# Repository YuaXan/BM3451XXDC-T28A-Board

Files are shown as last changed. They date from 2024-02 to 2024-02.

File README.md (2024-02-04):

<div align="center">
<h1>
<a href="https://github.com/YuaXan/BM3451XXDC-T28A-Board">BM3451XXDC-T28A-Board</a></h1>

**Rechargeable battery protection board based on BM3451 IC**
______________________________________________________________________








</div>

## Product Introduction
The board uses `BM3451XXDC-T28A` to protect 3/4/5 cells rechargeable battery pack. the IC works constantly to monitor each cell’s voltage, the current of charge or discharge, and the temperature of the environment to provide overcharge, over-discharge, discharge overcurrent, short circuit, charge overcurrent, and over-temperature protections, etc. Besides, it also can change the protection delay time of overcharge, over-discharge, and discharge overcurrent by setting the external capacitors.
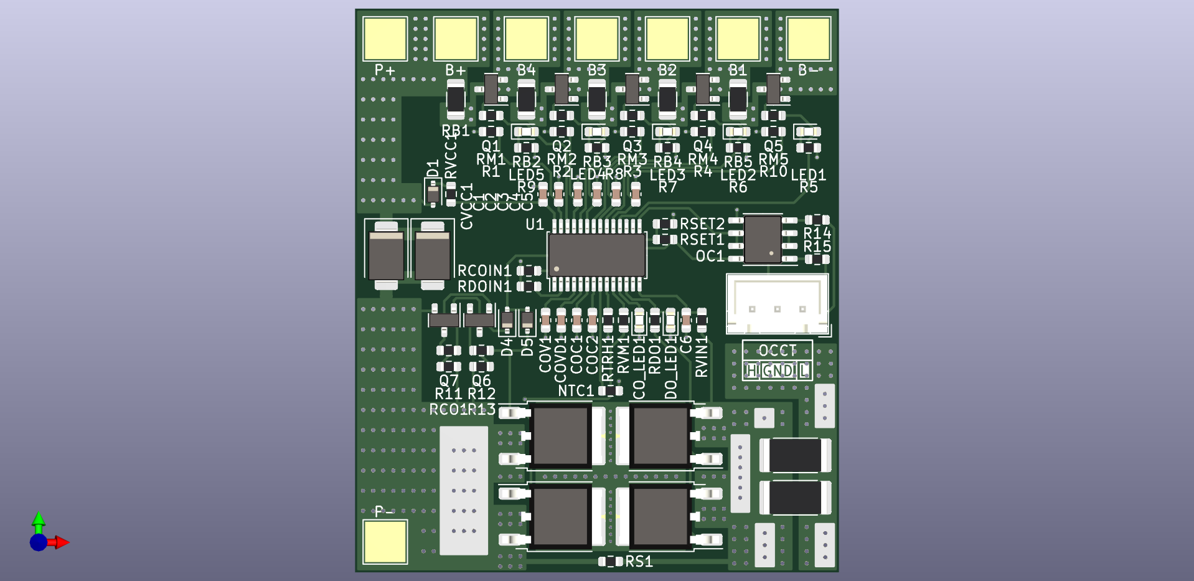
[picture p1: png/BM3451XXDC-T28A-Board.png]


## Application Scenarios
1. Power tools
2. Electric bicycle
3. UPS applications
4. etc.

## Product Description
The board's power supply voltage range is 5-30V, charge or discharge current MAX is 30A. 

The four MOSFET `Q8`, `Q9`, `Q10`, `Q11` and tow jepsun current resistor `RSENSE1` and `RSENSE2` can be replaced to achieve higher current output. 
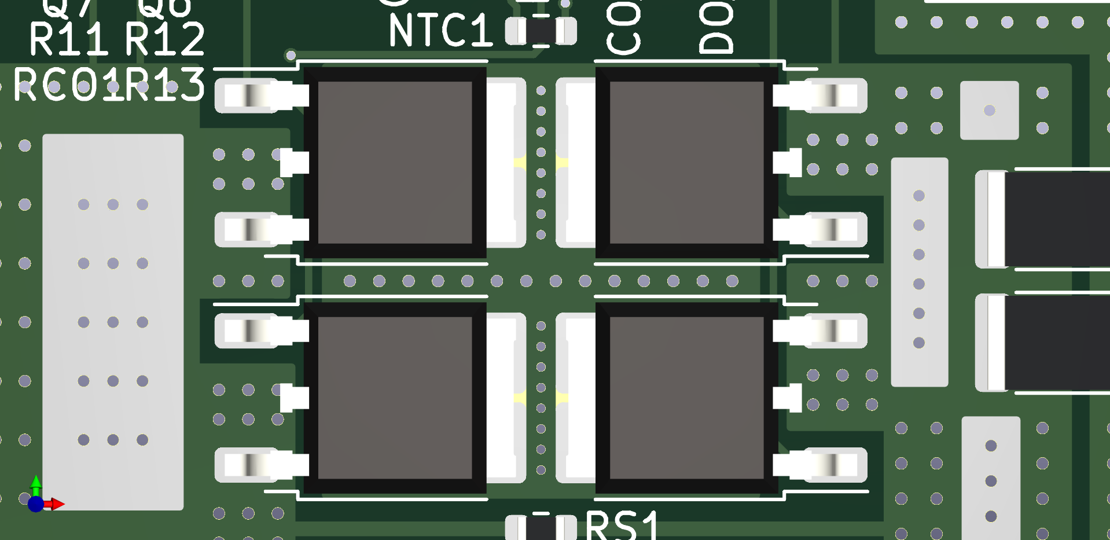
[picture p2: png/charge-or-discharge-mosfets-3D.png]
Charge or discharge mosfets 3D


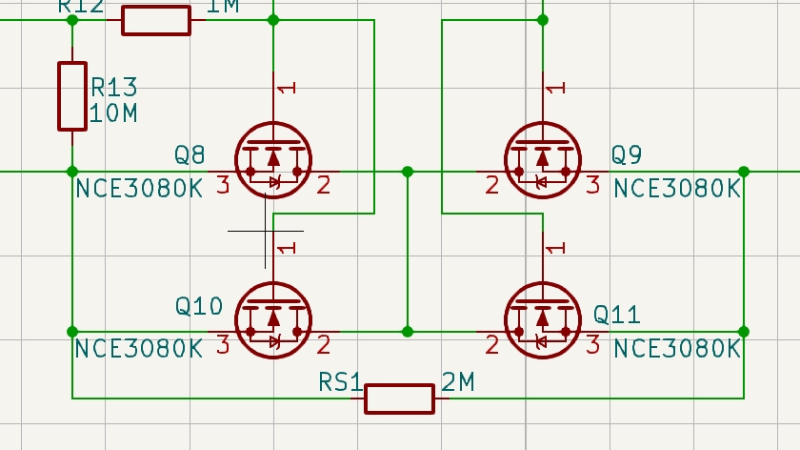
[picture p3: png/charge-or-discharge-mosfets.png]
Charge or discharge mosfets


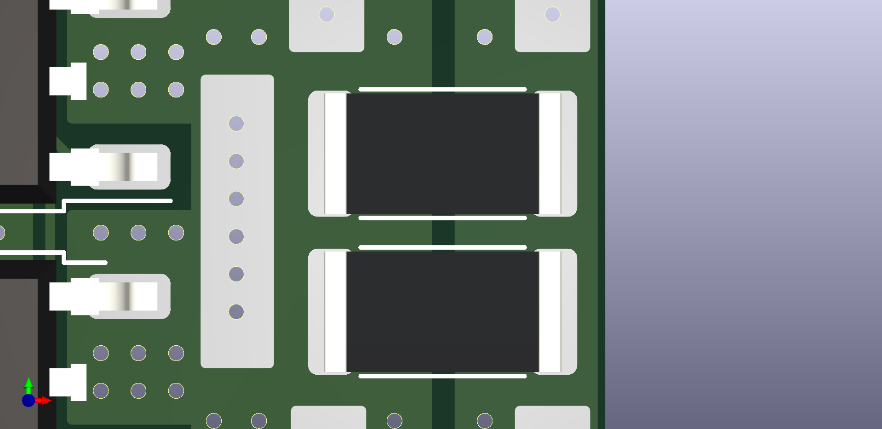
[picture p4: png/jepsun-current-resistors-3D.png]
Jepsun current resistors 3D


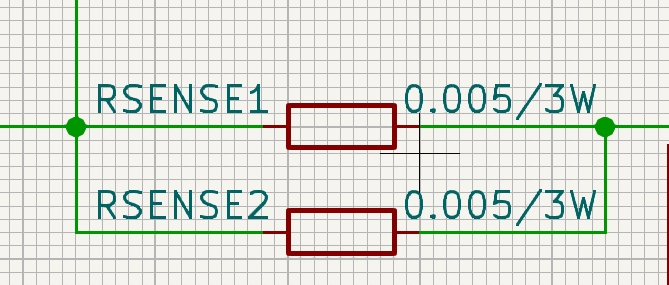
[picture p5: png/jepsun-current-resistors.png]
Jepsun current resistors


---

Select the number of cells based on whether `RSET1` and `RSET2` are mounted with 0Ω resistors.

When `RSET1` and `RSET2` all not mounting with 0Ω resistors leads to the `SET` pin in a floating state, and the board can connect 5 cells. 
When `RSET1` is mounting with resistors, `RSET2` is not mounting with resistors, and short circuits `B1` and `B-`, the board can connect 4 cells.
When `RSET1` is not mounting with resistors, and `RSET2` is mounting with resistors, and short circuits `B2`, `B1`, and `B-`, the board can connect 3 cells.

**[Warning]: Not `RSET1` and `RSET2` all to mounting with 0Ω resistors, this behavior will cause a short circuit**

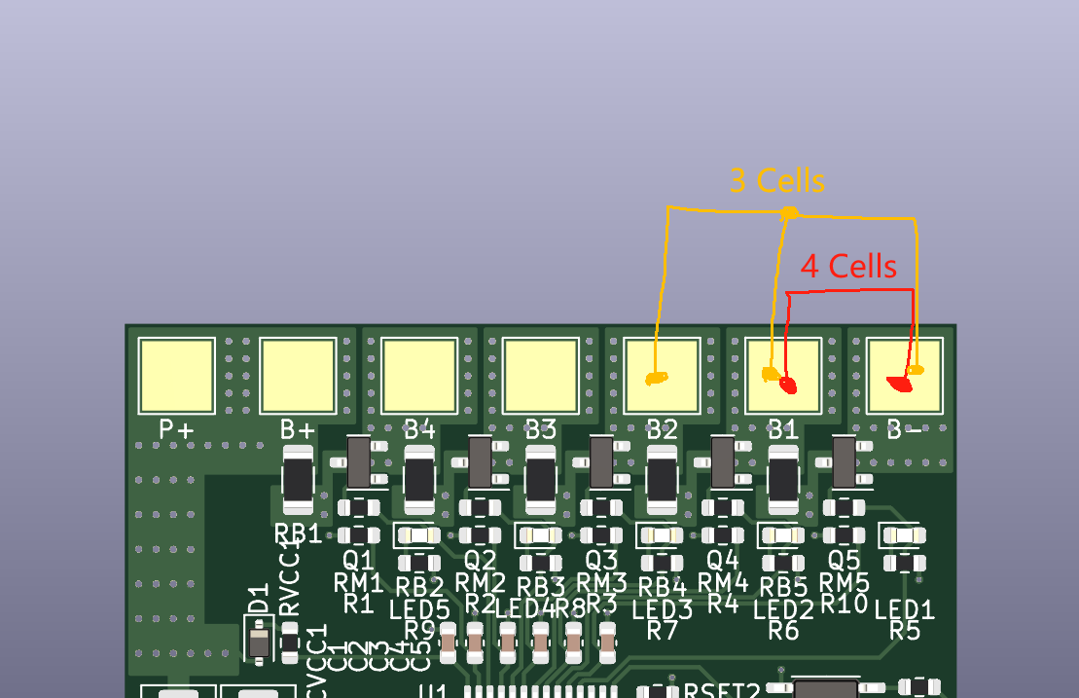
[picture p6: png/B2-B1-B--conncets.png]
B2/B1/B- Conncets


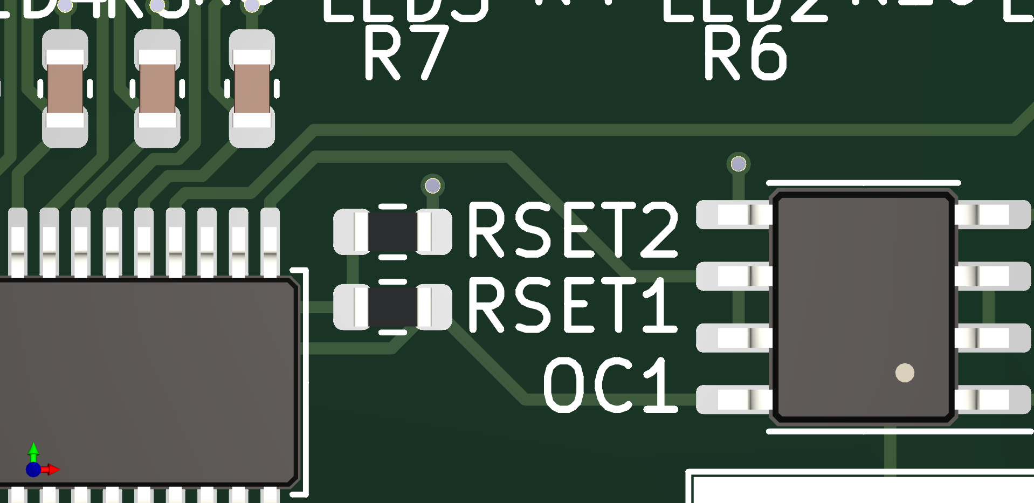
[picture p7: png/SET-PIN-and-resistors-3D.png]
SET PIN and resistors 3D


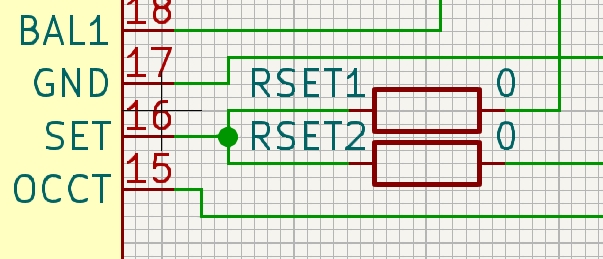
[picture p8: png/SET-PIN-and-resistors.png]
SET PIN and resistors


3/4/5 cells application selection

---

There are five LEDs to monitor the balancing status of the cells. When one of the LEDs is lit, it means that the corresponding cell is starting to balance. 
 
`LED1`, `LED2`, `LED3`, `LED4`, and `LED5` correspond to `B1`, `B2`, `B3`, `B4`, and `B5` respectively:
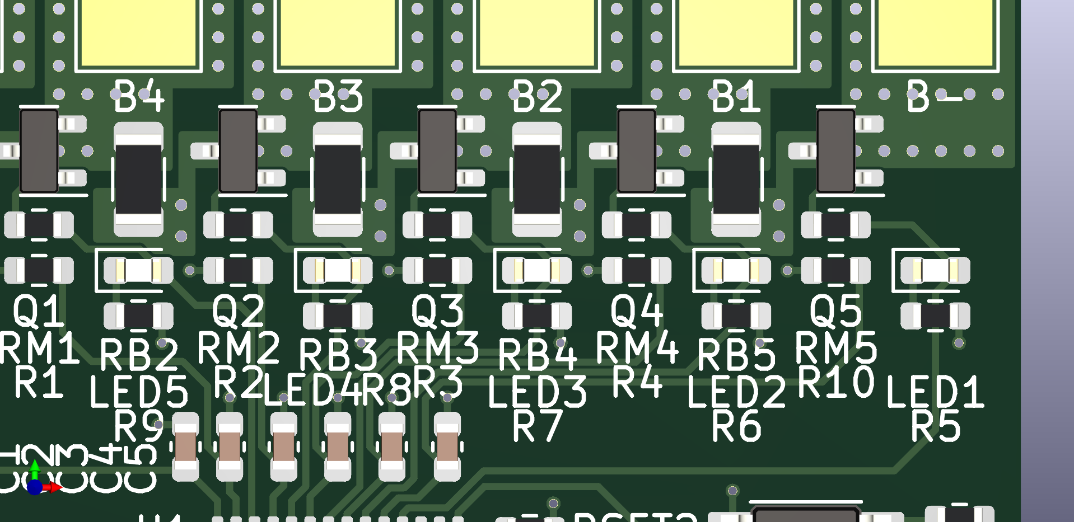
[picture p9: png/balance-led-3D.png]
balance led 3D


 ---
 
At the same time, the `DO` and `CO` pins correspond to `DO_LED1` and `CO_LED1` respectively. This allows you to check the discharge and charge status. 
 
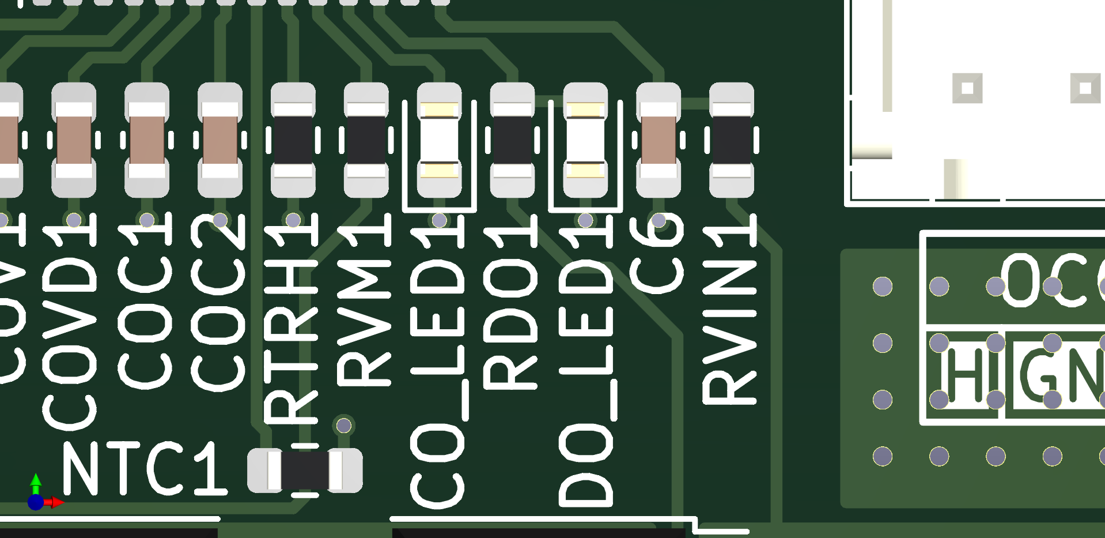
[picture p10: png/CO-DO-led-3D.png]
CO DO led 3D


 ---
 
Safe and reliable by providing control discharge overcurrent release terminals with optical coupler.

Control of `OCCT` pin is via `XH P2.5mm 3pin` terminal.

**[Warning]: The `OCCT` pin has not been tested. Usage instructions are not provided in the datasheet. Usage instructions will be provided after board testing.**

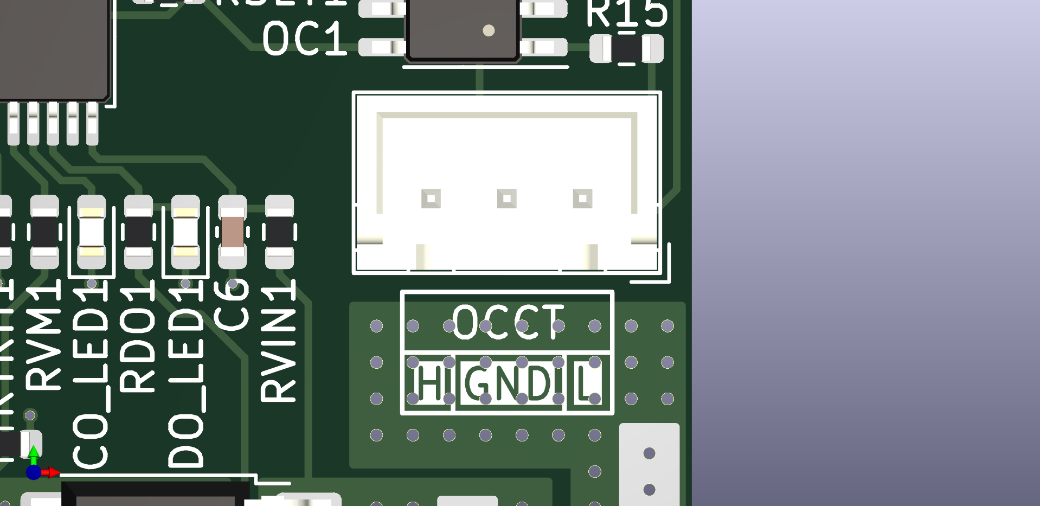
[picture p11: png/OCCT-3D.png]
OCCT 3D


## Instruction Manual
The board connection diagram is shown in the image.
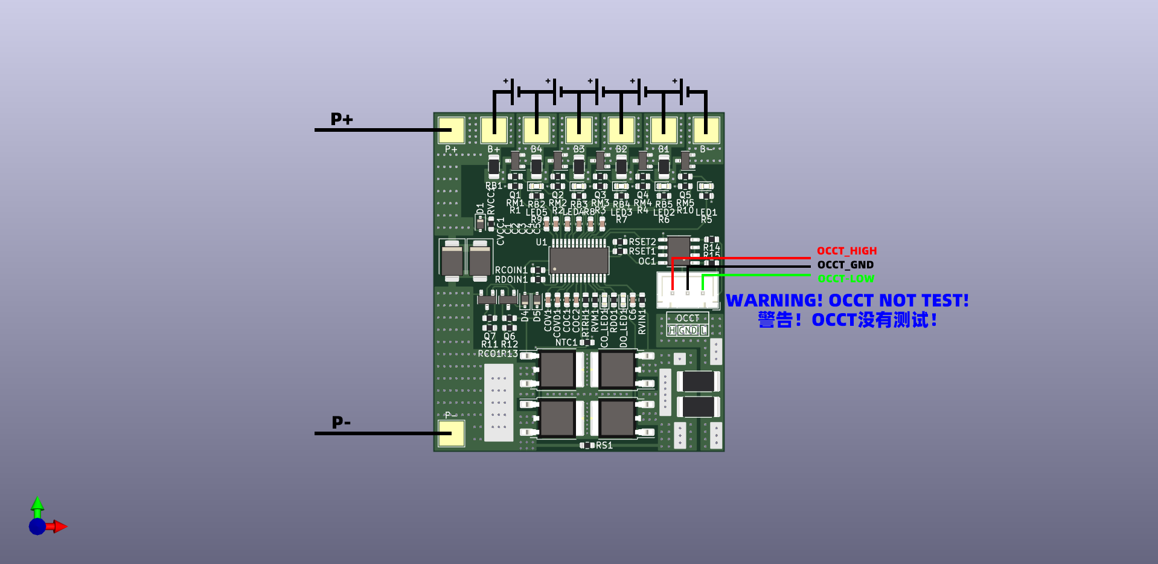
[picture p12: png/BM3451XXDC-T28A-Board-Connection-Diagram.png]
BM3451XXDC-T28A-Board Connection Diagram


## TODO
- [ ] The board is manufactured.
- [ ] The board is testing.
- [ ] Know how `OCCT` works.
- [ ] The donation channel is open.

## Contributions
Every contribution to this repository is highly appreciated! If you spot any bug or problem, open a issue or pull request so that it can be rectified for everyone.

For feature requests: Please open a issue and I'll add the feature in a future release once I get some time in my hands.

## Donors
The donation channel is not currently open, so stay tuned.

## License
For e-enthusiasts or geeks, follow the [CC-BY-NC-SA 4.0](/LICENSE.txt) license. For contributors and donors you can follow the [CC-BY 4.0](/LICENSE-CC-BY-4.0.txt) license, which means that commercial use is supported and distributed freely.

## Information
[BM3451XXDC-T28A DataSheet](http://www.bydmicro.com/params/field/preview/PDF_PRODUCT_202304141002.pdf)

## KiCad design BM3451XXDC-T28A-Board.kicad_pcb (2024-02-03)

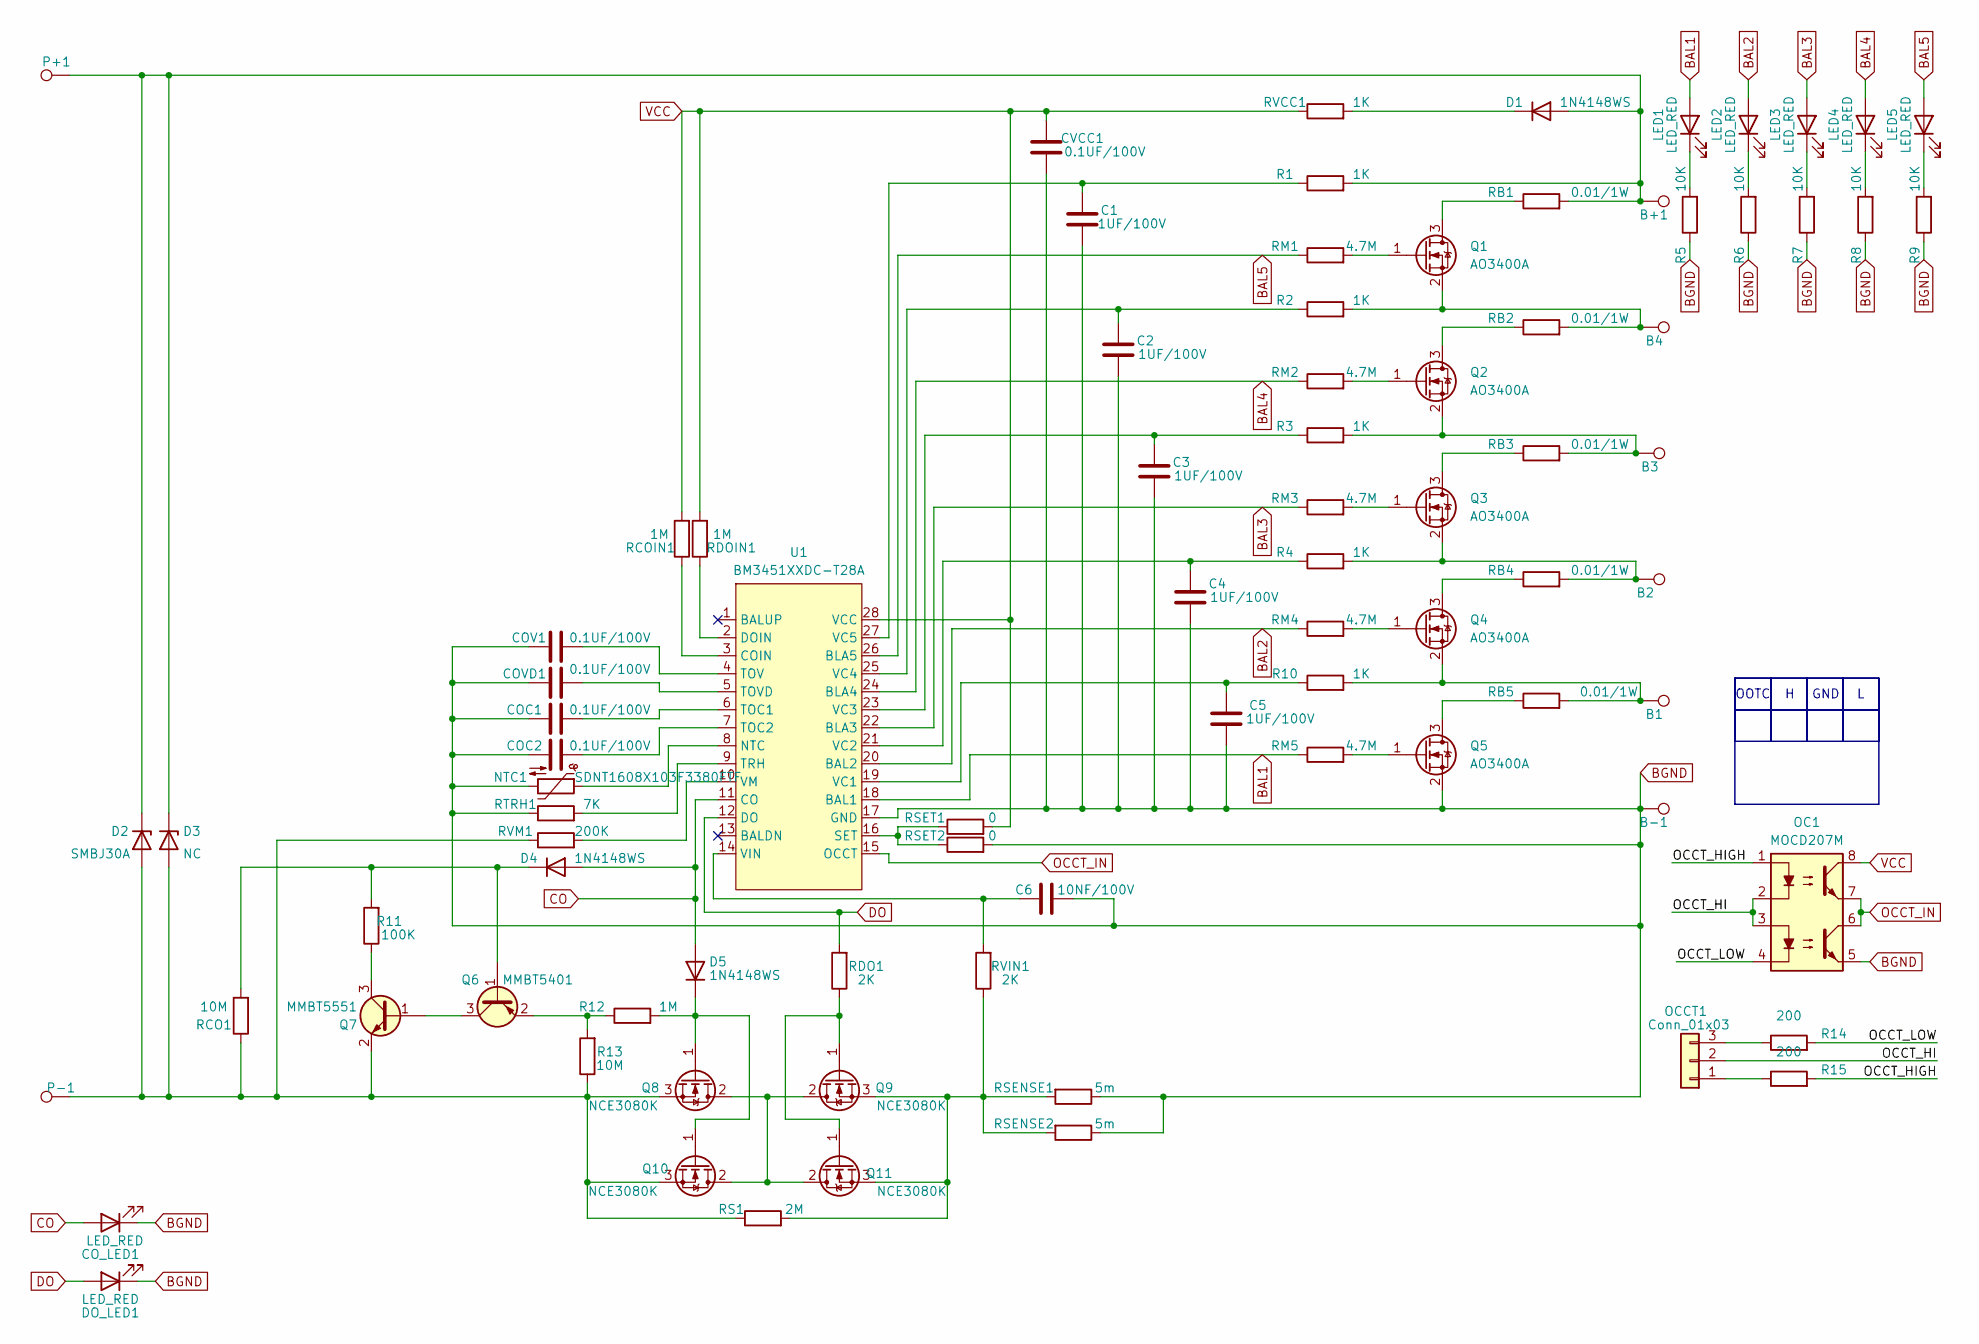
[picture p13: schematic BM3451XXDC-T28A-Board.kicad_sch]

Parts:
B1, B2, B3, B4: TestPoint; TestPoint_Pad_4.0x4.0mm
B+1: TestPoint; TestPoint_Pad_4.0x4.0mm
B-1: TestPoint; TestPoint_Pad_4.0x4.0mm
C1, C2, C3, C4, C5: 1UF/100V; C_0603_1608Metric
C6: 10NF/100V; C_0603_1608Metric
COC1, COC2: 0.1UF/100V; C_0603_1608Metric
COV1: 0.1UF/100V; C_0603_1608Metric
COVD1: 0.1UF/100V; C_0603_1608Metric
CO_LED1: LED_RED; LED_0603_1608Metric
CVCC1: 0.1UF/100V; C_0603_1608Metric
D1, D4, D5: 1N4148WS; D_SOD-323
D2: SMBJ30A; D_SMB
D3: NC; D_SMB
DO_LED1: LED_RED; LED_0603_1608Metric
LED1, LED2, LED3, LED4, LED5: LED_RED; LED_0603_1608Metric
NTC1: SDNT1608X103F3380FTF; R_0603_1608Metric
OC1: MOCD207M; SO-8_3.9x4.9mm_P1.27mm
OCCT1: Conn_01x03; JST_XH_B3B-XH-A_1x03_P2.50mm_Vertical
P+1: TestPoint; TestPoint_Pad_4.0x4.0mm
P-1: TestPoint; TestPoint_Pad_4.0x4.0mm
Q1, Q2, Q3, Q4, Q5: AO3400A; SOT-23
Q6: MMBT5401; SOT-23
Q7: MMBT5551; SOT-23
Q8, Q9, Q10, Q11: NCE3080K; TO-252-2
R1, R2, R3, R4, R10: 1K; R_0603_1608Metric
R5, R6, R7, R8, R9: 10K; R_0603_1608Metric
R11: 100K; R_0603_1608Metric
R12: 1M; R_0603_1608Metric
R13: 10M; R_0603_1608Metric
R14, R15: 200; R_0603_1608Metric
RB1, RB2, RB3, RB4, RB5: 0.01/1W; R_1206_3216Metric
RCO1: 10M; R_0603_1608Metric
RCOIN1: 1M; R_0603_1608Metric
RDO1: 2K; R_0603_1608Metric
RDOIN1: 1M; R_0603_1608Metric
RM1, RM2, RM3, RM4, RM5: 4.7M; R_0603_1608Metric
RS1: 2M; R_0603_1608Metric
RSENSE1, RSENSE2: 5m; R_2512_6332Metric
RSET1, RSET2: 0; R_0603_1608Metric
RTRH1: 7K; R_0603_1608Metric
RVCC1: 1K; R_0603_1608Metric
RVIN1: 2K; R_0603_1608Metric
RVM1: 200K; R_0603_1608Metric
U1: BM3451XXDC-T28A; TSSOP-28_4.4x9.7mm_P0.65mm

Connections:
/OCCT_HI: OC1.2, OC1.3, OCCT1.2; also elsewhere on the board
/OCCT_HIGH: OC1.1, R15.2
/OCCT_LOW: OC1.4, R14.2
BAL1: LED1.2 (A), RM5.1, U1.18 (BAL1)
BAL2: LED2.2 (A), RM4.1, U1.20 (BAL2)
BAL3: LED3.2 (A), RM3.1, U1.22 (BLA3)
BAL4: LED4.2 (A), RM2.1, U1.24 (BLA4)
BAL5: LED5.2 (A), RM1.1, U1.26 (BLA5)
BGND: B-1.1, C1.1, C2.1, C3.1, C4.1, C5.1, C6.1, COC1.1, COC2.1, COV1.1, COVD1.1, CO_LED1.1 (K), CVCC1.1, DO_LED1.1 (K), NTC1.2, OC1.5, Q5.2 (S), R5.1, R6.1, R7.1, R8.1, R9.1, RSENSE1.1, RSENSE2.1, RSET2.2, RTRH1.1, U1.17 (GND); also elsewhere on the board
CO: CO_LED1.2 (A), D4.2 (A), D5.2 (A), U1.11 (CO)
DO: DO_LED1.2 (A), RDO1.2, U1.12 (DO)
unnamed 11: B+1.1, D1.2 (A), D2.1 (K), D3.1 (K), P+1.1, R1.2, RB1.2; also elsewhere on the board
unnamed: D1.1 (K), RVCC1.2
unnamed 13: D2.2 (A), D3.2 (A), P-1.1, Q7.2 (E), Q8.3 (S), Q10.3 (S), R13.1, RCO1.1, RS1.1, RVM1.1; also elsewhere on the board
unnamed: D4.1 (K), Q6.1 (B), R11.2, RCO1.2
unnamed: D5.1 (K), Q8.1 (G), Q10.1 (G), R12.2
unnamed: LED1.1 (K), R5.2
unnamed: LED2.1 (K), R6.2
unnamed: LED3.1 (K), R7.2
unnamed: LED4.1 (K), R8.2
unnamed: LED5.1 (K), R9.2
unnamed 21: OCCT1.1, R15.1; also elsewhere on the board
unnamed 22: OCCT1.3, R14.1; also elsewhere on the board
unnamed: Q1.3 (D), RB1.1
unnamed: Q1.1 (G), RM1.2
unnamed: B4.1, Q1.2 (S), R2.2, RB2.2
unnamed: Q2.3 (D), RB2.1
unnamed: Q2.1 (G), RM2.2
unnamed: B3.1, Q2.2 (S), R3.2, RB3.2
unnamed: Q3.3 (D), RB3.1
unnamed: Q3.1 (G), RM3.2
unnamed: B2.1, Q3.2 (S), R4.2, RB4.2
unnamed: Q4.3 (D), RB4.1
unnamed: Q4.1 (G), RM4.2
unnamed: B1.1, Q4.2 (S), R10.2, RB5.2
unnamed: Q5.3 (D), RB5.1
unnamed: Q5.1 (G), RM5.2
unnamed: Q6.3 (C), Q7.1 (B)
unnamed: Q6.2 (E), R12.1, R13.2
unnamed: Q7.3 (C), R11.1
unnamed: Q8.2 (D), Q9.2 (D), Q10.2 (D), Q11.2 (D)
unnamed: Q9.1 (G), Q11.1 (G), RDO1.1
unnamed: Q9.3 (S), Q11.3 (S), RS1.2, RSENSE1.2, RSENSE2.2, RVIN1.1
unnamed: RCOIN1.1, U1.3 (COIN)
unnamed: RDOIN1.1, U1.2 (DOIN)
unnamed: NTC1.1, U1.8 (NTC)
unnamed: RSET1.1, RSET2.1, U1.16 (SET)
unnamed: COC1.2, U1.6 (TOC1)
unnamed: COC2.2, U1.7 (TOC2)
unnamed: COV1.2, U1.4 (TOV)
unnamed: COVD1.2, U1.5 (TOVD)
unnamed: RTRH1.2, U1.9 (TRH)
unnamed: C5.2, R10.1, U1.19 (VC1)
unnamed: C4.2, R4.1, U1.21 (VC2)
unnamed: C3.2, R3.1, U1.23 (VC3)
unnamed: C2.2, R2.1, U1.25 (VC4)
unnamed: C1.2, R1.1, U1.27 (VC5)
unnamed: C6.2, RVIN1.2, U1.14 (VIN)
unnamed: RVM1.2, U1.10 (VM)
OCCT_IN: OC1.6, OC1.7, U1.15 (OCCT)
VCC: CVCC1.2, OC1.8, RCOIN1.2, RDOIN1.2, RSET1.2, RVCC1.1, U1.28 (VCC)

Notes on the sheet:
GND
OOTC

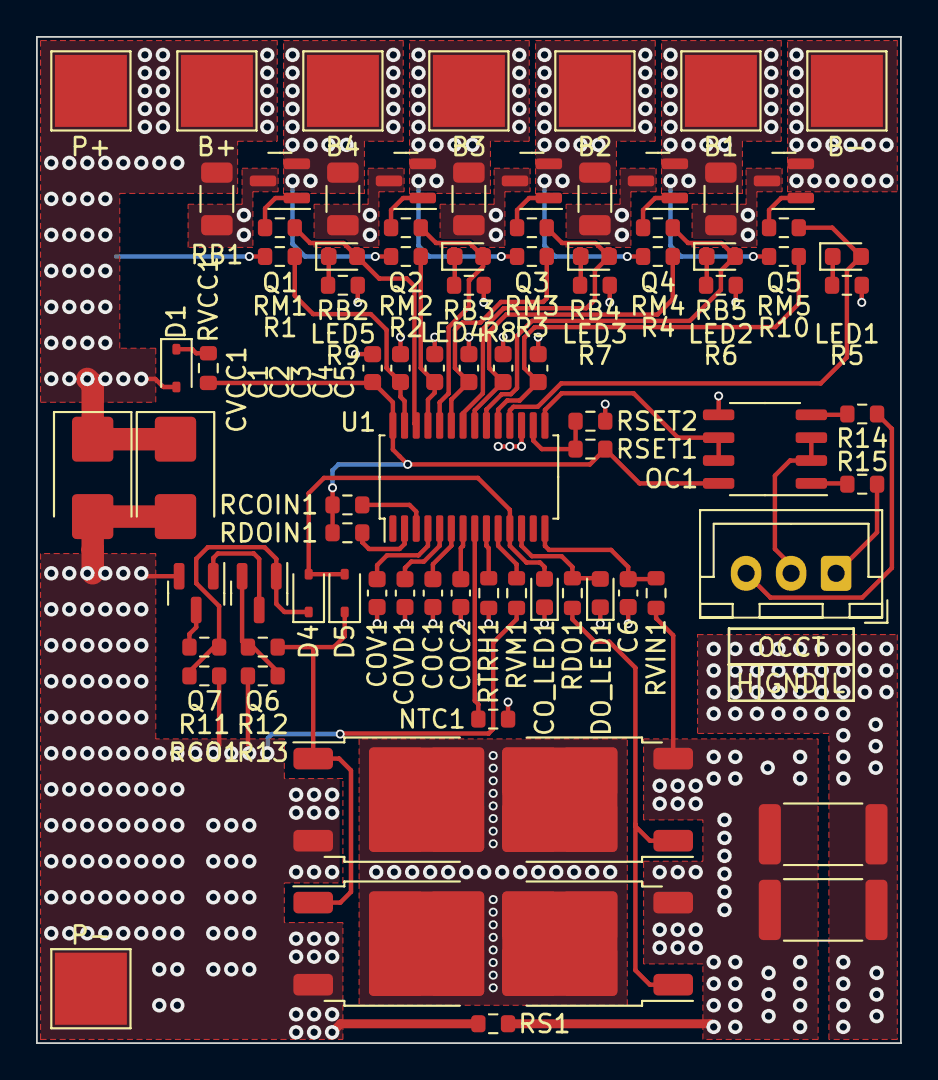
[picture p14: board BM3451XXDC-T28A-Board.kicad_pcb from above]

Board: 2 copper layers, 48.0 x 55.9 mm, 84 parts (0 on the bottom side), 61 nets.

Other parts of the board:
B+: TestPoint; TestPoint_Pad_4.0x4.0mm
B-: TestPoint; TestPoint_Pad_4.0x4.0mm
OCCT: Conn_01x03; JST_XH_B3B-XH-A_1x03_P2.50mm_Vertical
P+: TestPoint; TestPoint_Pad_4.0x4.0mm
P-: TestPoint; TestPoint_Pad_4.0x4.0mm

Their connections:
/OCCT_HI: OCCT.2; also elsewhere on the board
BGND: B-.1; also elsewhere on the board
unnamed 11: B+.1, P+.1; also elsewhere on the board
unnamed 13: P-.1; also elsewhere on the board
unnamed 21: OCCT.1; also elsewhere on the board
unnamed 22: OCCT.3; also elsewhere on the board

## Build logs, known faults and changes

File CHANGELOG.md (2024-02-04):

# Change Log

All notable changes to this project will be documented in this file.

The format is based on [Keep a Changelog](http://keepachangelog.com/)
and this project adheres to [Semantic Versioning](http://semver.org/).

## [v1.0] - 2024-02-05

- Initial release

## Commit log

2024-02-03 Change to a CC BY-NC-SA 4.0 License and add .gitignore
    [BM3451XXDC-T28A-Board.kicad_sch]
2024-02-04 Submit readme.md and some images
    [BM3451XXDC-T28A-Board.kicad_sch]

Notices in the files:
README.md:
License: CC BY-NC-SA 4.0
